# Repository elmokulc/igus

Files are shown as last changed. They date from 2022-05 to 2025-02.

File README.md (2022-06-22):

# IGUS : Linear Motion Device controlled by Arduino
Author: O. PERIA
---
## Linear module Features

- Part No. : STL-BB-0412
- Pitch : 1.5 mm (Tr08 x 1.5)

## Stepper motor Features

- Part No. : 17HM15-0904S (NEMA 17)
- Step angle : 0.9° (400 steps per revolution)

## Motor controller board Features

- Ref. : uStepper
-  Arduino compatible board with integrated stepper driver and 16-bit rotary encoder
- Limitswitch connected to pin PD2 (Digital input 2)

## Main commands

- H or H# : Moving Home
- P or P# : Getting current absolute step Position
- S or S# : Emmergency Stop
- h of h# : Printing Help
- R#[arg] : Moving [arg] steps Right - Example: R#10000
- L#[arg] : Moving [arg] steps Left

## Sources 
- Hardware : 
  - Seller website : [here](https://www.ustepper.com/getting-started-with-ustepper/)
  - Plugin to add to Arduino IDE: 
    - "ustepperS"
  - Additional Boards Managers URLS to add on Arduino IDE: 
    - [https://raw.githubusercontent.com/uStepper/uStepperHardware/master/package_ustepper_index.json](https://raw.githubusercontent.com/uStepper/uStepperHardware/master/package_ustepper_index.json)

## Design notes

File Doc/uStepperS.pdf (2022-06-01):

# uStepper S

# Product sheet

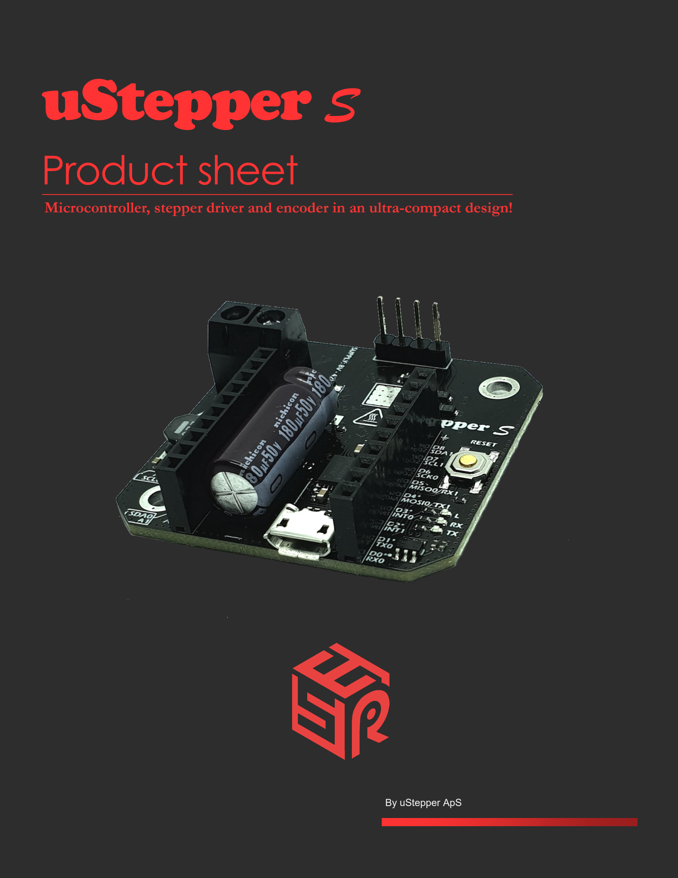
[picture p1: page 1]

By uStepper ApS

Microcontroller, stepper driver and encoder in an ultra-compact design!

Product: uStepper S

Document revision: 1.4

Author: MGN

Approved by: THO

Approval date: November 19th 2019 uStepper S incorporates a super silent stepper driver, high resolution encoder and Arduino

compatible MCU in a super slim design!

- Program uStepper with ease using the Arduino IDE and our extensive Arduino library !
- Make your stepper motor applications extremely compact !
- Make sure that you never miss a step again, thanks to the on-board encoder and control algorithm !

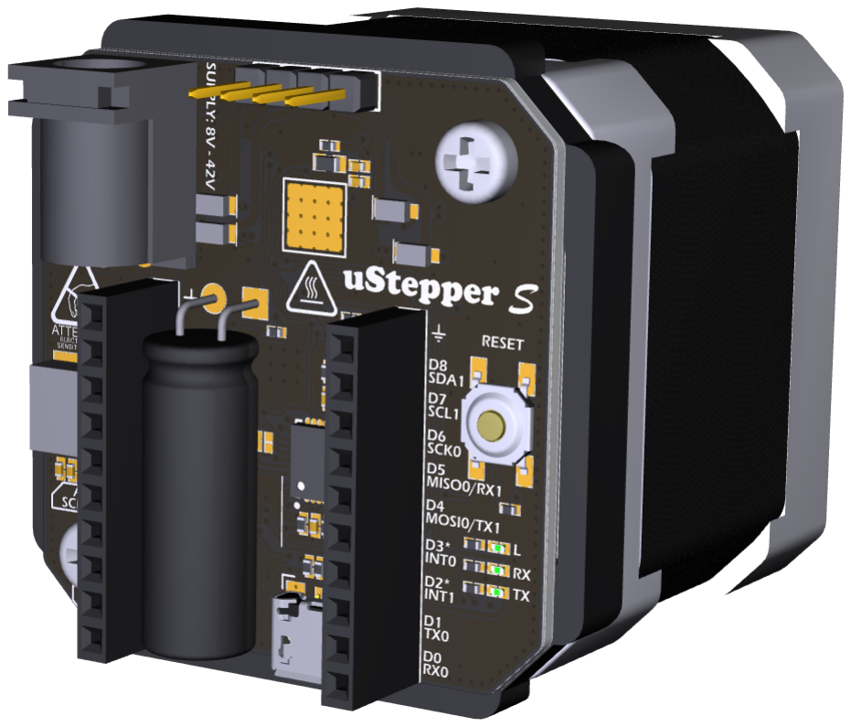
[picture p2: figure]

The super slim design of uStepper S makes it possible to develop applications using a stepper motor, without the need for long and messy wiring to an external Arduino/stepper shield. Furthermore the 16-bit rotary encoder ensures that the absolute position of the motor shaft can be tracked, enabling the uStepper S to detect any loss of steps and act on it !

## System overview

## uStepper S features

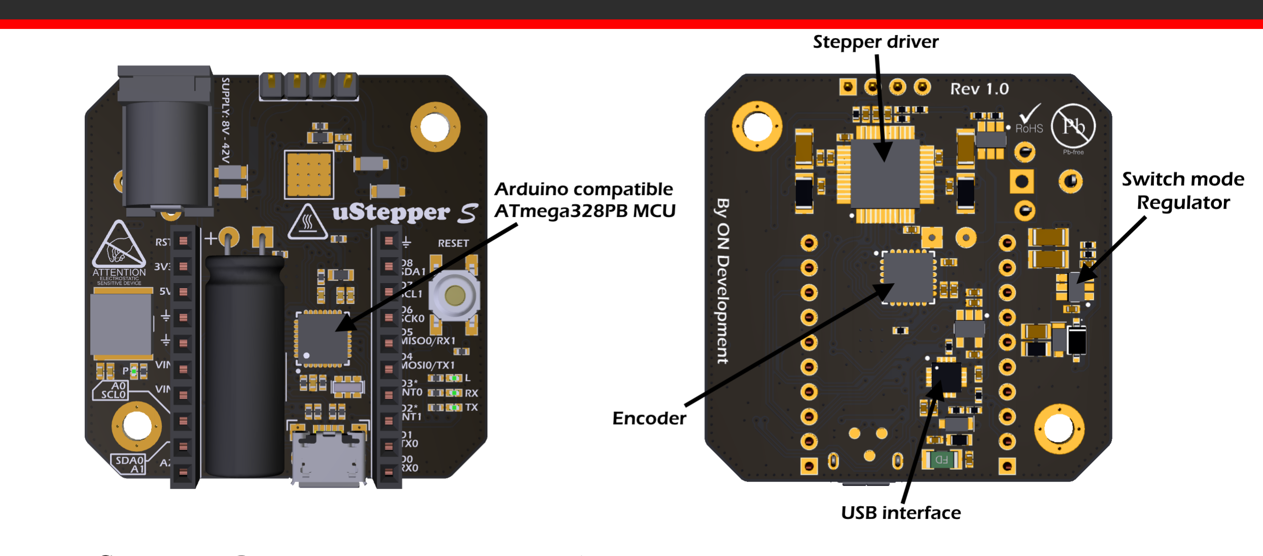
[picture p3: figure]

uStepper S has the following highlighted features:

- Compact design, fitting on the back of a NEMA 17 size stepper motor (41.8 mm x 41.8 mm)
- Incorporates the Trinamic TMC5130 with dynamic microstepping for very smooth operation with integrated ramp generator
- Driver delivers 2.5 A current (peak)
- New upgraded 328PB MCU from Microchip
- 16-bit encoder (0.0055 degrees resolution)
- Drive current is software controllable
- 12 I/O
- 3 Analog, 5 PWM
- 1 x SPI , 2 x UART, 2 x I2C
- Supply voltage 8 - 42 V
- Reverse polarity protection

Even though uStepper S features reverse polarity protection, it is always advisable to check the polarity before supplying power to the board in order to prevent damaging the board.

MCU

uStepper S uses the successor of the well tested and widely used ATmega328P - the ATmega328PB. Why? Because it does the job and does it good! The new upgraded ATmega328PB has been upgraded on multiple points including double USART, double I2C, double SPI and upgraded timers !

Stepper driver chip

The TMC5130 is a serious powerhouse and features a native 1/256th microstepping processing engine, complete with acceleration and deceleration ramping profiles, to give smooth transition to the desired speed. The native 1/256th microstepping not only ensures low noise levels and smooth operation, it also improves the precision of your application, by reducing the smallest step size of the motor to an astonishing 0.007 degrees (assuming a motor with 200 steps per revolution)! To put this into perspective, if the motor was mounted onto a CNC machine, where the axis moves 10 mm per full rotation, this would correspond to a resolution of 0.195 microns !

Encoder
The uStepper S uses the AEAT8800-Q24 encoder from Broadcom, delivering 16 bits resolution corresponding to 0.0055 degrees ! This is a perfect match for the TMC5130 with it’s native high resolution microstepping since this sensors is able to detect deviations just below the step resolution - enabling uStepper S to compensate properly.

Switch mode regulator
uStepper S Incorporates a switch mode regulator for delivering the 5 V logic supply. This is done to ensure that a supply voltage of up to 42 V can be applied ! The relatively high supply voltage has the benefit of increasing the stepper drivers ability to overcome the back EMF voltage generated by the motor, and hereby increasing the available torque at increasing velocities, compared to lower supply voltages.

## uStepper S features

## uStepper S pin mapping

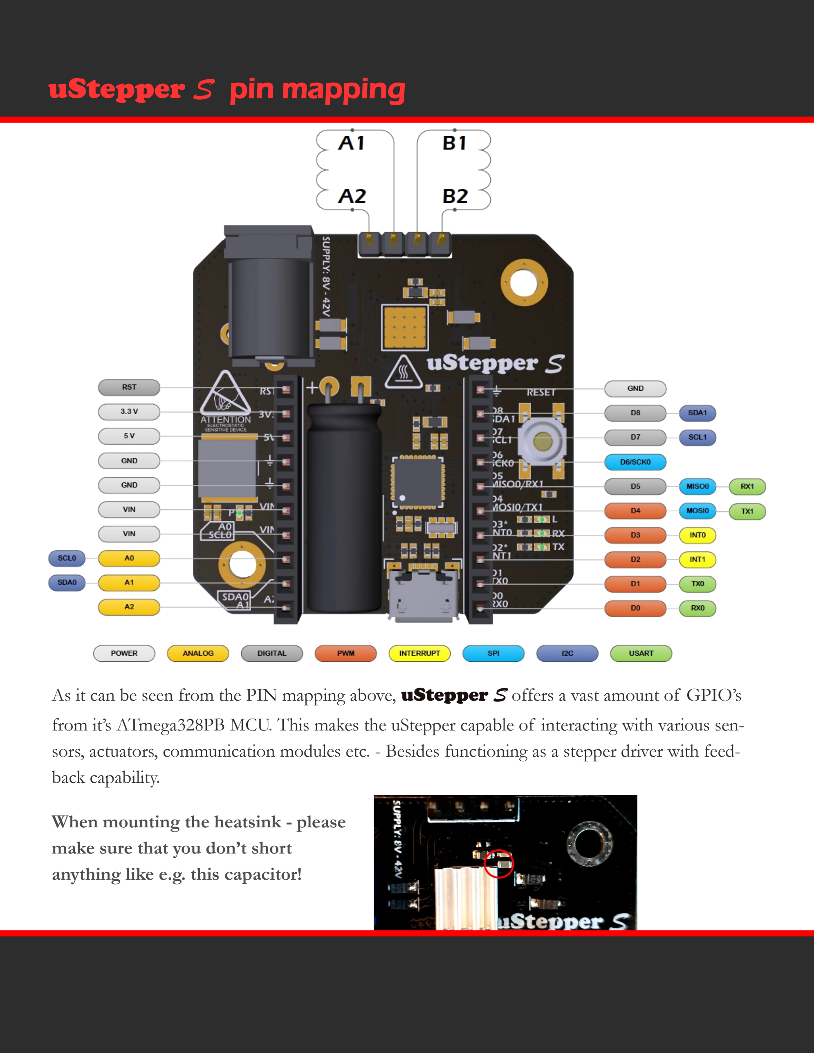
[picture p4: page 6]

As it can be seen from the PIN mapping above, uStepper S offers a vast amount of GPIO’s from it’s ATmega328PB MCU. This makes the uStepper capable of interacting with various sensors, actuators, communication modules etc. - Besides functioning as a stepper driver with feedback capability.

When mounting the heatsink - please
make sure that you don’t short anything like e.g. this capacitor!

## uStepper S characteristics

I/O Voltage | 5 V
Input Voltage (recommended) | 8 - 42 V
DC Current per I/O Pin (max) | 40 mA (max 200 mA total I/O draw)
DC Current for 5 V Pin (max) | 1000 mA
DC Current for 3.3 V Pin (max) | 150 mA
Stepper drive current | Up to 2.5 A (peak)
Dimensions | 41.8 x 41.8 x 14.5 mm
Weight | ~15g

Physical characteristics

Electrical characteristics

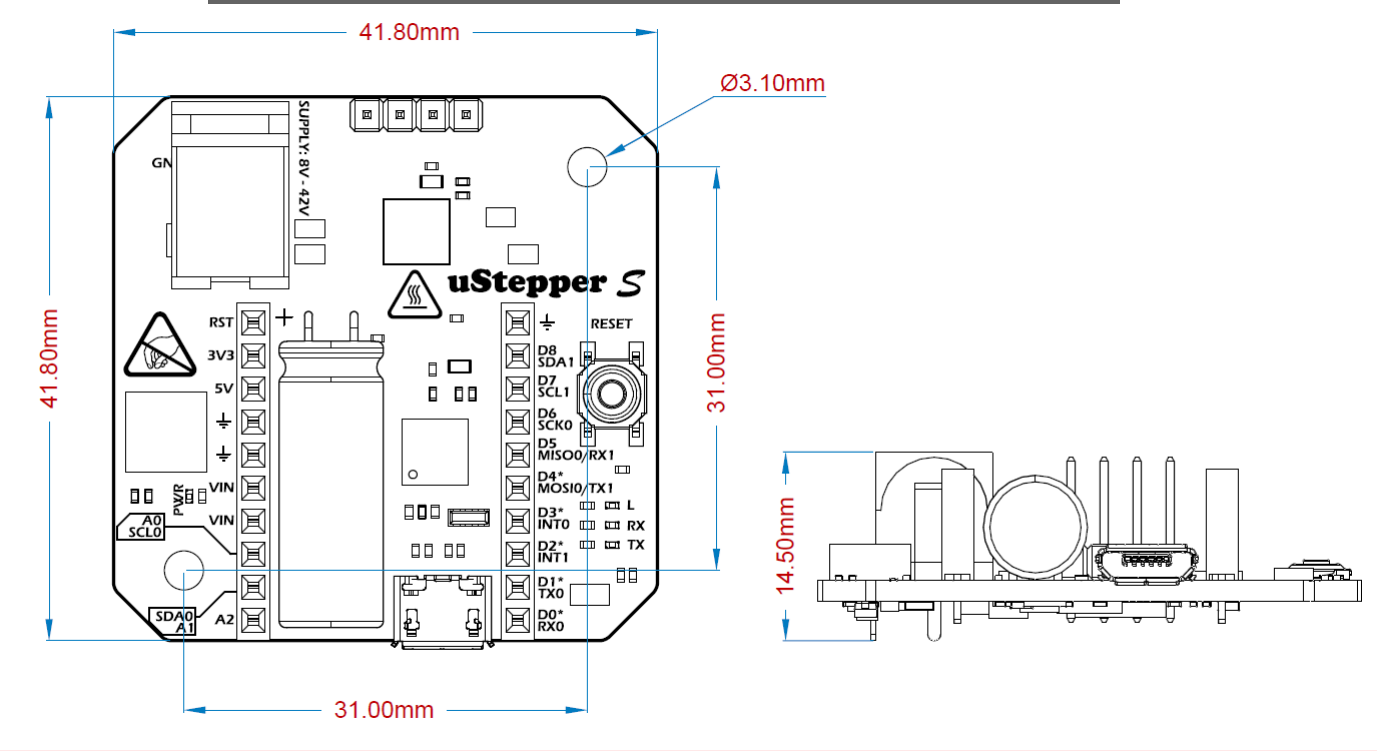
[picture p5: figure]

## uStepper S mounting

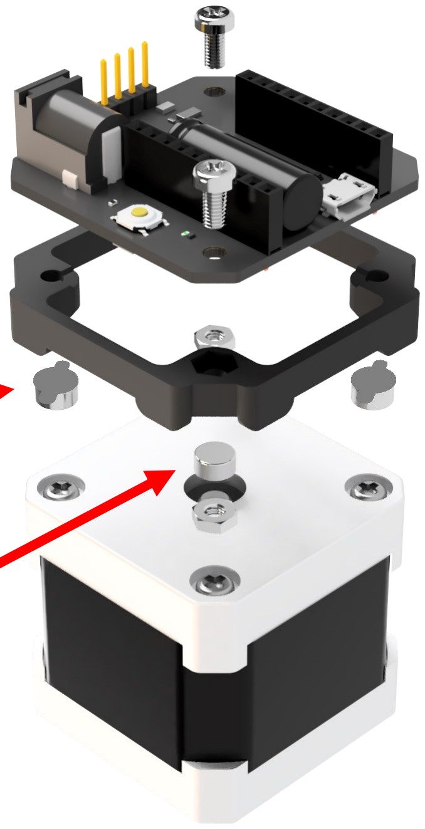
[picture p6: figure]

Diametrically magnetized encoder magnet

uStepper S comes with a bracket allowing two ways of mounting - magnet or permanent.

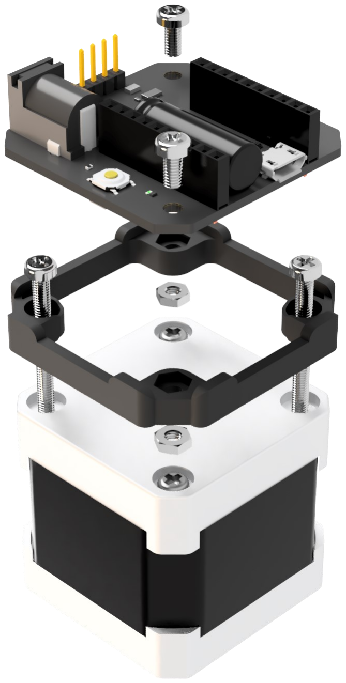
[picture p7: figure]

Permanent mount:

1.Remove two motor screws

2.Place encoder magnet on motor shaft

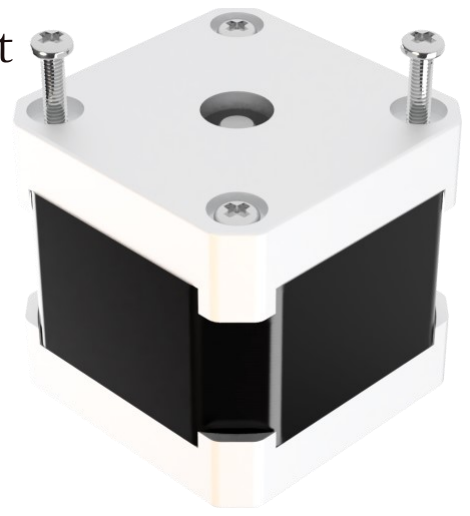
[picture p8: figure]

3.Insert nuts into bracket and mount bracket to motor w. two long screws

4.Secure uStepper S to the bracket with

Magnet mount:

1.Place encoder magnet on motor shaft

2.Add adhesive tape to mounting magnets

3.Insert mounting magnets into bracket

4.Secure uStepper S to the bracket with

## uStepper S FAQ

For information on how to setup uStepper in the Arduino IDE, visit our GitHub repository at www.github.com/uStepper or have a look at our videos on YouTube - search for uStepper.

More information/documentation on the uStepper Arduino library is also found in the readme section on out GitHub repository.

Q: I can’t program uStepper from the Arduino IDE, what is wrong?

A: Three most common issues:

1. If you use the Windows store app “Arduino IDE” you might experience problems. Download the executable or portable version of Arduino IDE from www.arduino.cc
2. Install hardware support and the uStepper S library
3. Remember to chose uStepper S as the board you program to

Q: When I run uStepper closed loop PID or Drop-in the motor spins up and runs fast in one direction, what is wrong?

A: Two most common issues:

1. Check that the encoder magnet is placed correctly on the motor shaft
2. Check that your PID parameters in the Arduino code are sane. A good starting point is to set P and I to 0.5 and D to 0.

For more FAQ visit www.ustepper.com !

## uStepper S getting started !

To get starter using uStepper S visit our instructive videos and GitHub documentation page pro-

vided below !

On GitHub you will see descriptions on how to set up uStepper S in the Arduino IDE and also find a link to the complete Arduino library documentation !

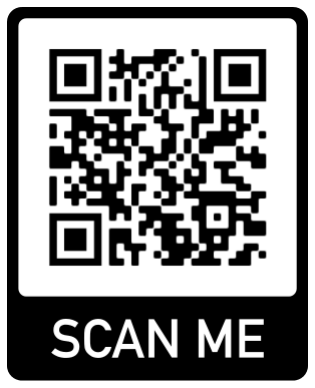
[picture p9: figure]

PRESS HERE (https://github.com/uStepper/uStepperS) to get to our GitHub or scan the code on the right !

Video Tutorials

On our YouTube channel you will find video tutorials on how to mount uStepper S, setting it up in the Arduino IDE and programming it. You will also find cool projects and application examples for uStepper S !

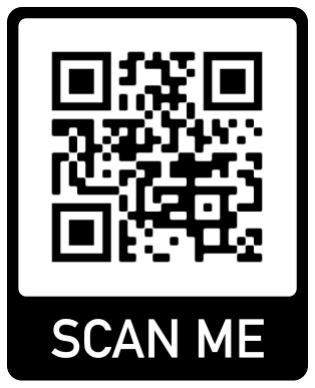
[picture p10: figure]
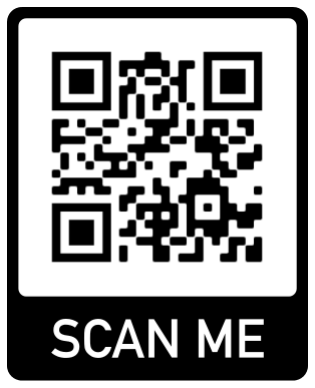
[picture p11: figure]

Mounting uStepper S (https://youtu.be/oYFnBv0kocI) | Programming uStepper S (https://youtu.be/V5M66Nhyn5s)

## uStepper S applications

Because of low cost and reliability stepper motors are favored over servo drives in a variety of ap-

plications, as for example robots, CNC machines, 3D-printers etc. With added feedback uStepper

can add a new dimension to stepper operation utilizing closed loop control or correction of

missed steps - making the stepper even more appealing than a more costly servo drive. With the

numerous features and the vast amount of I/O’s (including various busses), uStepper is the choice

for DIY hobbyists when in need of a reliable, precise and compact actuator for almost any applica-

tion.

Almost unlimited applications and ease of programming using the Arduino IDE also makes uStep-

per well suited for educational purposes !

### ”After all, learning just gets a bit more fun when there’s movement involved!”

## Disclaimer

1 Disclaimers and Limitation of Liability

1.1 uStepper ApS and/or ON Development IVS (or any individuals affiliated with either of the two companies) can not be held responsible for any damage inflicted upon mounting or interfacing with the uStepper board. This also includes damage to stepper motor (both electrical and mechanical) or any other 3rd party hardware connected to uStepper. Most stepper motor cases are made of aluminum, and care must be taken when preparing the mountings for uStepper.

1.2 By using the uStepper products (including, but not limited to, hardware and software) you acknowledge that uStepper ApS and/or ON Development IVS (or any individuals affiliated with either of the two companies) can not be held responsible for any personal injuries and/or damage to any 3rd party hardware that may occur when using the uStepper products.

1.3 To the extent permitted by law, uStepper ApS and/or ON Development IVS will not be liable for any indirect or consequential loss or damage, of any kind, (including without limitation loss of business, opportunity, data, profits) arising out of or in connection with the use of any products (including, but not limited to, hardware and software), developed, produced or sold by uStepper ApS and/or ON Development IVS (or any individuals affiliated with either of the two companies).

1.4 Nothing in these Terms and Conditions shall be construed so as to hold uStepper ApS and/or ON Development IVS liable for death or personal injury as a result of the negligence of uStepper ApS and/or ON Development IVS or that of its employees or agents.

2 Indemnity

2.1 You agree to indemnify and hold uStepper ApS and/or ON Development IVS and its employees and agents harmless from and against all liabilities, legal fees, damages, losses, costs and other expenses in relation to any claims or actions brought against uStepper ApS and/or ON Development IVS arising out of any breach by you of these Terms and Conditions or other liabilities arising out of your use of this Website.

2.2 You agree to indemnify and hold uStepper ApS and/or ON Development IVS and its employees and agents harmless from and against all liabilities, legal fees, damages, losses, costs and other expenses in relation to any claims or actions brought against uStepper ApS and/or ON Development IVS arising out of any breach by you of these Terms and Conditions or other liabilities arising out of your use of products(including, but not limited to, hardware and software) developed, produced or sold by uStepper ApS and/or ON Development IVS (or any individuals affiliated with either of the two companies).

3 Severance

If any of these Terms and Conditions should be determined to be invalid, illegal or unenforceable for any reason by any court of competent jurisdiction then such Term or Condition shall be severed and the remaining Terms and Conditions shall survive and remain in full force and effect and continue to be binding and enforceable.

## Contact

uStepper ApS
sales@ustepper.com

www.uStepper.com

© 2019 uStepper ApS All Rights Reserved

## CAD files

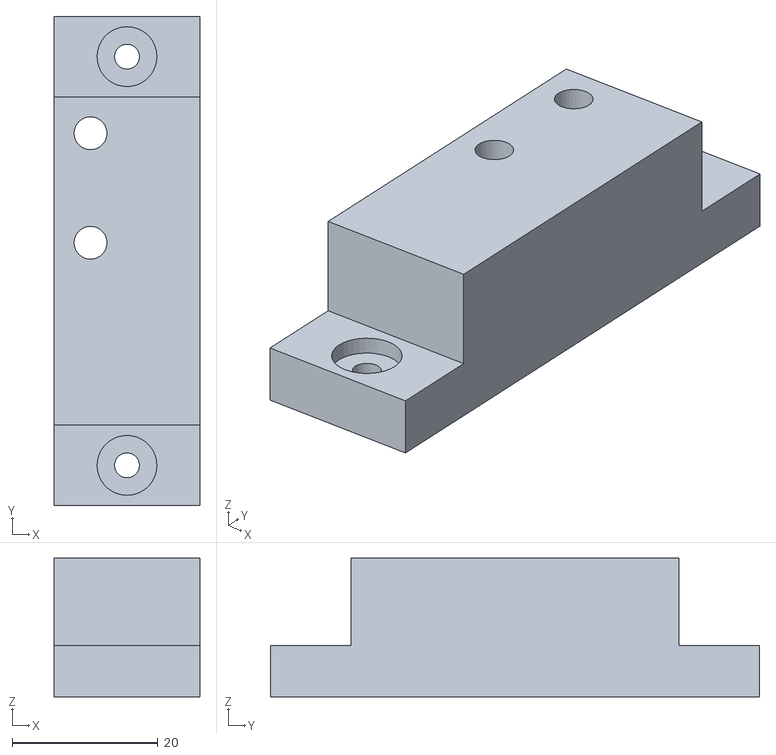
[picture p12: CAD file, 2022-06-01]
STL/TP_BASE_GAUCHE_02.STL
20.0 x 67.0 x 19.0

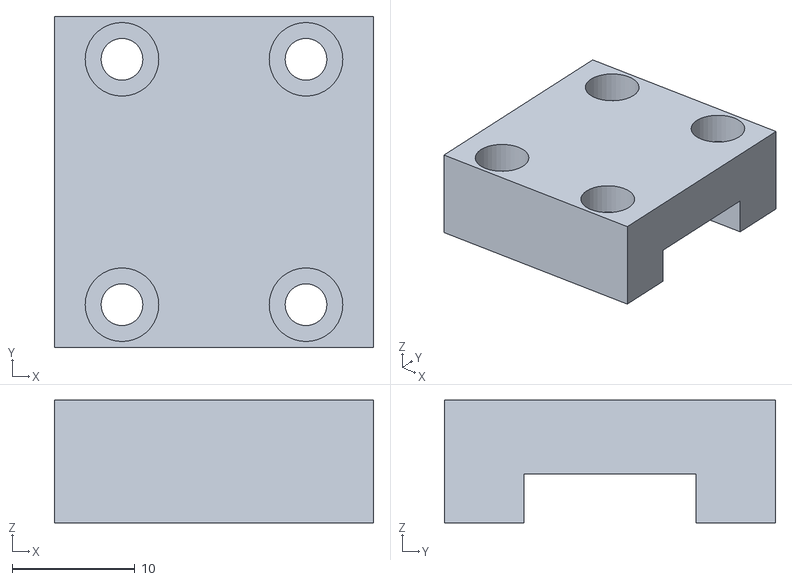
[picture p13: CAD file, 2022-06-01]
STL/TP_BUTEE_SWITCH_01.STL
26.0 x 27.0 x 10.0

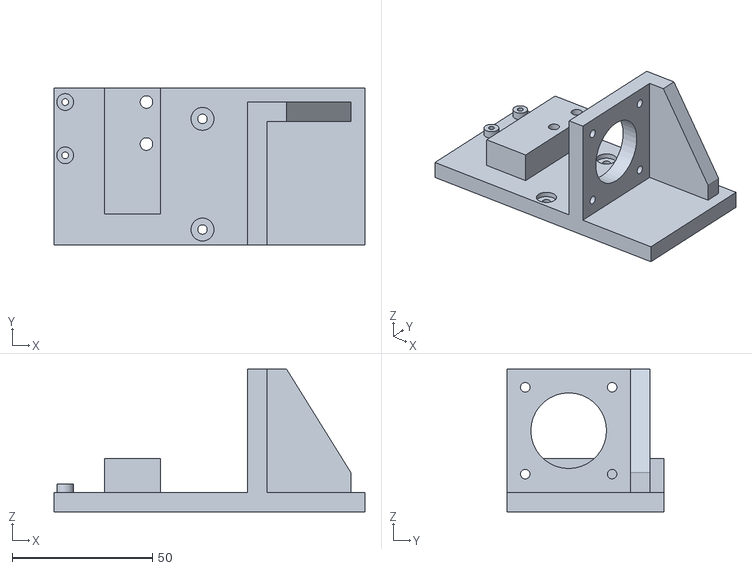
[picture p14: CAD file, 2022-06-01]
STL/TP_BASE_DROITE_02.STL
111.0 x 56.0 x 51.0

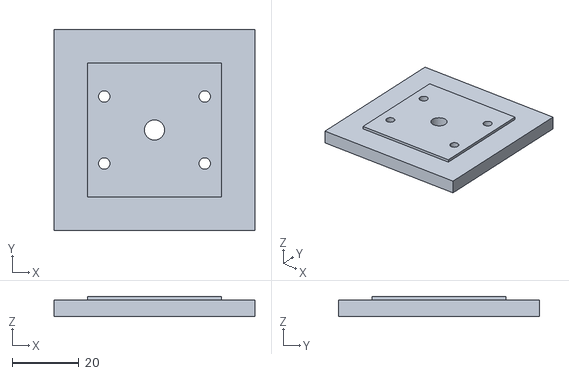
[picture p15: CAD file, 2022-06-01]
STL/TP_PLATEAU_01.STL
60.0 x 60.0 x 6.00

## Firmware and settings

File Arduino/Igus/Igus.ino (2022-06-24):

/********************************************************************************************
 *        File: Igus.ino                                                                     *
 *     Version: 1.0 Initial release                                                          *
 *        Date: May 19th, 2022                                                               *
 *      Author: Olivier PERIA                                                                *
 * Description: Drives Linear Motion Module IGUS                                             *
 *    Features: Possible commands sent to serial line :                                      *
 *                 H or H# : Moving Home                                                     *
 *                 P or P# : Getting current absolute step Position                          *
 *                 S or S# : Emmergency Stop                                                 *
 *                 h of h# : Printing Help                                                   *
 *                 R#[arg] : Moving [arg] steps Right - Example: R#10000                     *
 *                 L#[arg] : Moving [arg] steps Left                                         *
 ********************************************************************************************/

#include "Umotor.h"

#define LIMIT_STEP_MIN 0     // Motor Home position
#define LIMIT_STEP_MAX 45000 // Motor maximum position

#define VELOCITY_SLOW 200 // Slow velocity (steps/s)

#define ACCELERATION_SLOW 200  // Slow acceleration (steps/s^2)
#define ACCELERATION_FAST 1000 // Fast acceleration (steps/s^2)

#define LIMIT_SWITCH PD2 // Limit switch pin

#define CMD_DELIMITER '#' // Deliliter character
#define CMD_GOTORIGHT "R" // command : Move Right
#define CMD_GOTOLEFT "L"  // command : Move Left
#define CMD_GOHOME "H"    // command : Move Home
#define CMD_STOP "S"      // command : Emergency Stop
#define CMD_POSE "P"      // command : Get current absolute step Position
#define CMD_MODE "M"      // command : Request to change mode
#define CMD_HELP "h"      // command : Help

#define SET_VF "VF" // Set velocity fast

#define ACK_READY "READY"
#define ACK_START "MOVING..."
#define ACK_HOME "HOME POSITION"
#define ACK_INIT "MOVE HOME FIRST"
#define ACK_REACHED "POSITION REACHED"
#define ACK_WAIT "INVALID COMMAND WHILE MOVING"
#define ACK_ERROR "SYNTAX ERROR"
#define ACK_INVALID "INVALID ARGUMENT"
#define ACK_OUTRANGE "ARGUMENT OUT OF RANGE"
#define ACK_ABORTED "ABORTED"
#define ACK_RESET "MOTOR MUST BE RESETED"
#define ACK_DONE "CMD DONE"

#define MD_LINEAR 0
#define MD_ROTATE 1

typedef struct
{
  int32_t absSteps = 0; // Absolute step position (target position)
  int32_t nSteps = 0;   // Relative step position

} step_rcd;

Umotor stepperMotor(LIMIT_SWITCH); // Instantiates stepperMotor object with limit switch connected to LIMIT_SWITCH pin

step_rcd stepCntr; // Step counter (absolute and relative position)

uint8_t mMode; // Motor mode

int32_t VELOCITY_FAST = 100; // Fast velocity (steps/s) VMAX = 3000
uint8_t WK_MODE = MD_LINEAR; // Working mode can be : "MD_LINEAR", "MD_ROTATE" or "MD_SETUP"

/********************************************************************************************
 * Initializes the stepper motor and moves to initial position                               *
 ********************************************************************************************/
void setup()
{

  Serial.begin(9600);     // Sets the data rate for serial data transmission to 9600 baud
  Serial.setTimeout(100); // sets the maximum milliseconds to wait for serial data to 500

  // Setup stepperMotor
  stepperMotor.setup(NORMAL, STEP_REVOLUTION); // Normal mode (see Arduino UstepperS library)

  // Set stepperMotor driver direction
  stepperMotor.driver.setShaftDirection(1); // Inverted direction

  // Set motor brake mode when motor is stopped
  stepperMotor.setBrakeMode(COOLBRAKE);

  Serial.println(ACK_READY);
}

/********************************************************************************************
 * Main loop                                                                                 *
 ********************************************************************************************/
void loop()
{
  // Reads and interprets the commands sent to serial line
  if (Serial.available())
    commandInterpreter(&stepperMotor, &stepCntr);

  if (WK_MODE == MD_LINEAR)
  {
    // Lost steps detection and correction
    mMode = stepperMotor.getMotorMode();
    if ((mMode != MOTOR_INIT) && (mMode != MOTOR_ABORTED))
    {
      // Motor not checked and Driver position reached
      if ((mMode != MOTOR_CHECKED) && (stepperMotor.getMotorState(POSITION_REACHED) == 0))
      {
        // Updates absolute step position
        if (mMode == MOTOR_RUNNING_RIGHT)
          stepCntr.absSteps += stepCntr.nSteps;
        else if (mMode == MOTOR_RUNNING_LEFT)
          stepCntr.absSteps -= stepCntr.nSteps;
        // Checks and corrects lost steps
        checkSteps(&stepperMotor, &stepCntr);
        Serial.println(ACK_REACHED);
      }
    }
  }
  else if (WK_MODE == MD_ROTATE)
  {
    // Lost steps detection and correction
    mMode = stepperMotor.getMotorMode();
    if (mMode != MOTOR_ABORTED)
    {
      // Motor not checked and Driver position reached
      if ((mMode != MOTOR_CHECKED) && (stepperMotor.getMotorState(POSITION_REACHED) == 0))
      {
        // Updates absolute step position
        if (mMode == MOTOR_RUNNING_RIGHT)
          stepCntr.absSteps += stepCntr.nSteps;
        else if (mMode == MOTOR_RUNNING_LEFT)
          stepCntr.absSteps -= stepCntr.nSteps;
        // Checks and corrects lost steps
        // checkSteps(&stepperMotor, &stepCntr);
        stepperMotor.setMotorMode(MOTOR_CHECKED);
        Serial.println(ACK_REACHED);
      }
    }
  }
}

/********************************************************************************************
 * Reads and interprets the commands sent to serial line                                     *
 *                                                                                           *
 * input : motor : stepper motor                                                             *
 *         pose  : absolute and relative step positions                                      *
 ********************************************************************************************/
void commandInterpreter(Umotor *motor, step_rcd *pose)
{
  // Gets motor mode
  uint8_t mMode = motor->getMotorMode();

  // If motor aborted after emergency stop command sent
  if (mMode == MOTOR_ABORTED)
  {
    Serial.println(ACK_RESET);
    String str = Serial.readString(); // Clear serial buffer
  }

  // Else motor normaly stopped and checked
  else
  {
    // Gets the String read from the serial buffer, up to the delimiter character CMD_DELIMITER if found, or the entire
    // buffer if not found (after timeout defined in setup()). The delimiter character is not returned in the string
    String cmdString = Serial.readStringUntil(CMD_DELIMITER);

    // Command Emergency Stop
    if (cmdString.equals(CMD_STOP))
    {
      motor->stop(HARD);
      motor->setMotorMode(MOTOR_ABORTED);
      Serial.println(ACK_ABORTED);
    }

    // Command Move Right
    else if (cmdString.equals(CMD_GOTORIGHT))
    {
      // Motor normally stopped and checked
      if (mMode == MOTOR_CHECKED)
      {
        // Looks for the next valid integer in the serial buffer, returns 0 if not found (after timeout defined in setup())
        pose->nSteps = int32_t(Serial.parseInt());
        if (WK_MODE == MD_LINEAR){
            if (pose->nSteps <= 0)
              Serial.println(ACK_INVALID);
            else if ((pose->absSteps + pose->nSteps) > LIMIT_STEP_MAX)
              Serial.println(ACK_OUTRANGE);
            else
            {
              Serial.println(ACK_START);
              motor->rotateSteps(pose->nSteps, DIR_RIGHT, ACCELERATION_FAST, VELOCITY_FAST);
            }
          }
        else if (WK_MODE == MD_ROTATE){
            if (pose->nSteps <= 0)
              Serial.println(ACK_INVALID);
            else
            {
              Serial.println(ACK_START);
              motor->rotateSteps(pose->nSteps, DIR_RIGHT, ACCELERATION_FAST, VELOCITY_FAST);
            }
          }
      }
      // Motor must moved Home first
      else if (mMode == MOTOR_INIT)
      {
        Serial.readString(); // Clear serial buffer
        Serial.println(ACK_INIT);
      }
      // Motor moving
      else
      {
        Serial.readString(); // Clear serial buffer
        Serial.println(ACK_WAIT);
      }
    }

    // Command Move Left
    else if (cmdString.equals(CMD_GOTOLEFT))
    {
      // Motor normally stopped and checked
      if (mMode == MOTOR_CHECKED)
      {
        // Looks for the next valid integer in the serial buffer, returns 0 if not found (after timeout defined in setup())
        pose->nSteps = int32_t(Serial.parseInt());
        if (WK_MODE == MD_LINEAR){
            if (pose->nSteps <= 0)
              Serial.println(ACK_INVALID);
            else if ((pose->absSteps + pose->nSteps) > LIMIT_STEP_MAX)
              Serial.println(ACK_OUTRANGE);
            else
            {
              Serial.println(ACK_START);
              motor->rotateSteps(pose->nSteps, DIR_LEFT, ACCELERATION_FAST, VELOCITY_FAST);
            }
          }
        else if (WK_MODE == MD_ROTATE){
            if (pose->nSteps <= 0)
              Serial.println(ACK_INVALID);
            else
            {
              Serial.println(ACK_START);
              motor->rotateSteps(pose->nSteps, DIR_LEFT, ACCELERATION_FAST, VELOCITY_FAST);
            }
          }
      }
      // Motor must move Home first
      else if (mMode == MOTOR_INIT)
      {
        Serial.readString(); // Clear serial buffer
        Serial.println(ACK_INIT);
      }
      // Motor moving
      else
      {
        Serial.readString(); // Clear serial buffer
        Serial.println(ACK_WAIT);
      }
    }

    // Command Move Home
    else if (cmdString.equals(CMD_GOHOME))
    {
      // Motor normally stopped and checked
      if ((mMode == MOTOR_INIT) || (mMode == MOTOR_CHECKED))
      {
        Serial.println(ACK_START);
        MoveToInitialPosition(motor, pose);
        Serial.println(ACK_HOME);
      }
      // Motor moving
      else
      {
        Serial.readString(); // Clear serial buffer
        Serial.println(ACK_WAIT);
      }
    }

    // Command Get Absolute Step Position
    else if (cmdString.equals(CMD_POSE))
    {
      // Motor must move Home first
      if (mMode == MOTOR_INIT)
      {
        Serial.readString(); // Clear serial buffer
        Serial.println(ACK_INIT);
      }
      else
        Serial.println(stepperMotor.getEncoderSteps());
    }

    // Command Help
    else if (cmdString.equals(CMD_HELP))
    {
      Serial.println("H or H# : Moving Home");
      Serial.println("P or P# : Getting current absolute step Position");
      Serial.println("S or S# : Emmergency Stop");
      Serial.println("h of h# : Printing Help");
      Serial.println("R#[arg] : Moving [arg] steps Right - Example: R#10000");
      Serial.println("L#[arg] : Moving [arg] steps Left");
      Serial.println("M#[arg] : Switch mode 0=LINEAR 1=ROTATE - Example: M#0");
      Serial.println("VF#[arg] : Set max velocity (max=3000) - Example: VF#1000");
    }

    else if (cmdString.equals(CMD_MODE))
    {

      WK_MODE = int32_t(Serial.parseInt());
      Serial.readString(); // Clear serial buffer
      String workMode = GetWorkMode(WK_MODE);
      Serial.print(ACK_DONE);
      Serial.print(" Mode=");
      Serial.println(workMode);
    }

    else if (cmdString.equals(SET_VF))
    {

      VELOCITY_FAST = int32_t(Serial.parseInt());
      Serial.readString(); // Clear serial buffer
      Serial.print(ACK_DONE);
      Serial.print(" VELOCITY_FAST=");
      Serial.println(VELOCITY_FAST);
    }

    // Command not found
    else
      Serial.println(ACK_ERROR);
  }
}

/********************************************************************************************
 * Moves the carriage to initial position                                                    *
 *                                                                                           *
 * input : motor : stepper motor                                                             *
 *         pose  : rbsolute and relative step positions                                      *
 ********************************************************************************************/
void MoveToInitialPosition(Umotor *motor, step_rcd *pose)
{
  int32_t nMstps;

  // Set motor acceleration and velocity
  motor->setMaxAcceleration(ACCELERATION_FAST); // Fast acceleration
  motor->setMaxVelocity(VELOCITY_FAST);         // Fast velocity

  // Move carriage left to limit switch
  if (!motor->getLimitSwitchState())
  {                           // Limit switch not pressed
    motor->runContinous(CCW); // Move carriage left
    while (!motor->getLimitSwitchState())
      ;                // Wait for limit switch pressed
    motor->stop(HARD); // Stop carriage
  }

  // Move carriage 600 steps right
  motor->rotateSteps(600, DIR_RIGHT, ACCELERATION_FAST, VELOCITY_FAST);

  // Wait for motor stopped
  while (motor->getMotorState(POSITION_REACHED))
    ;

  // Set motor acceleration and velocity
  motor->setMaxAcceleration(ACCELERATION_SLOW); // Slow acceleration
  motor->setMaxVelocity(VELOCITY_SLOW);         // Slow velocity

  // Move carriage left to limit switch
  if (!motor->getLimitSwitchState())
  {                           // Limit switch not pressed (HIGH)
    motor->runContinous(CCW); // Move carriage left
    while (!motor->getLimitSwitchState())
      ;                // Wait for limit switch pressed
    motor->stop(HARD); // Stop carriage
  }

  // Move carriage 800 steps right
  motor->rotateSteps(800, DIR_RIGHT, ACCELERATION_SLOW, VELOCITY_SLOW);

  // Wait for position reached
  while (motor->getMotorState(POSITION_REACHED))
    ;

  // Reset driver and encoder step counters
  motor->driver.setHome();
  motor->encoder.setHome();

  // Reset motor step positions
  pose->absSteps = 0;
  pose->nSteps = 0;

  // Activates Motor brake
  motor->setBrakeMode(COOLBRAKE);

  // Set motor mode to CHECKED (target position reached)
  motor->setMotorMode(MOTOR_CHECKED);
}

/********************************************************************************************
 * Lost steps detection and correction                                                       *
 *                                                                                           *
 * Compares the encoder step counter (real position) with the motor step counter (target     *
 * position). If different, move the motor to make the encoder step position equal to the    *
 * motor step position                                                                       *
 *                                                                                           *
 * input : motor : stepper motor                                                             *
 *         pose  : absolute and relative step positions                                      *
 ********************************************************************************************/

void checkSteps(class Umotor *motor, step_rcd *pose)
{
  // Error between Motor target step position and Encoder real step position
  int32_t deltaSteps = pose->absSteps - motor->getEncoderSteps();

  while (deltaSteps != 0)
  {

    if (deltaSteps > 0)
      motor->rotateSteps(deltaSteps, DIR_RIGHT, ACCELERATION_FAST, VELOCITY_FAST); // Move right
    else
      motor->rotateSteps(int32_t(-1) * deltaSteps, DIR_LEFT, ACCELERATION_SLOW, VELOCITY_SLOW); // Move left

    while (motor->getMotorState(POSITION_REACHED))
      ; // Wait for position reached

    deltaSteps = pose->absSteps - motor->getEncoderSteps();
  }

  motor->setMotorMode(MOTOR_CHECKED);
}

/********************************************************************************************
 * Change distance to steps                                                                  *
 *                                                                                           *
 *  input : dist : distance in mm                                                            *
 * return : fullsteps                                                                        *
 ********************************************************************************************/
int32_t DistanceToSteps(float dist)
{
  int32_t nStps = int32_t(0.5 + dist * float(STEP_REVOLUTION) / 1.5); // 1.5 mm per revolution

  return (nStps);
}

String GetWorkMode(int MODE)
{
  String str;
  if (MODE == 0)
    str = "LINEAR";
  else
    str = "ROTATE";
  return str;
}

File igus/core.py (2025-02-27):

import serial
from threading import Thread
from functools import wraps
from time import sleep
import glob 
import sys
import logging


LOG_DEFAULT_FORMATTER = logging.Formatter(
    "[%(asctime)s:%(levelname)s:%(filename)s:%(lineno)d:%(funcName)s()]: [%(message)s]"
)

def serial_ports():
    """ Lists serial port names

        :raises EnvironmentError:
            On unsupported or unknown platforms
        :returns:
            A list of the serial ports available on the system
    """
    if sys.platform.startswith('win'):
        ports = ['COM%s' % (i + 1) for i in range(256)]
    elif sys.platform.startswith('linux') or sys.platform.startswith('cygwin'):
        # this excludes your current terminal "/dev/tty"
        ports = glob.glob('/dev/tty[A-Za-z]*')
    elif sys.platform.startswith('darwin'):
        ports = glob.glob('/dev/tty.*')
    else:
        raise EnvironmentError('Unsupported platform')

    result = []
    for port in ports:
        try:
            s = serial.Serial(port)
            s.close()
            result.append(port)
        except (OSError, serial.SerialException):
            pass
    return result

def thrd(f):
    ''' This decorator executes a function in a Thread'''
    @wraps(f)
    def wrapper(*args, **kwargs):
        thr = Thread(target=f, args=args, kwargs=kwargs)
        thr.start()
        
    return wrapper

class IGUS:
    def __init__(self, port='/dev/ttyUSB0', baudrate=9600, timeout=1):
        self.port = port
        self.baudrate = baudrate
        self.timeout = timeout       
        self.on_move = False
        self.pattern_flag = False
        self.pass_check = False
        self.CONST_REV = 0.00375 # mm/step
        
        self.warning_words = [
        "ACK_WAIT"    ,
        "ACK_ERROR"      ,
        "ACK_INVALID"   ,
        "ACK_OUTRANGE"  ,
        "ACK_ABORTED"   ,
        "ACK_RESET"]

        self.setup_logger()        
        self.connect()  
    
    def setup_logger(self):
        # Configuration du logger
        self.logger = logging.getLogger(f"{IGUS.__name__}")
        handler = logging.StreamHandler()  # Sortie des logs sur la console
        handler.setFormatter(LOG_DEFAULT_FORMATTER)
        self.logger.addHandler(handler)
        self.logger.setLevel(logging.INFO)  # Niveau par défaut
        self.logger.propagate = False  # Évite la duplication des logs
    
    def update_constant_rev(self, nb_step_per_tr=400, dist_per_tr=1.5):
        """_summary_

        Args:
            nb_step_per_tr (int, optional): Number of motor step to make one tour. Defaults to 400.
            dist_per_tr (float, optional): Displacement for one motor tour expressed in mm. Defaults to 1.5.
        """
        self.CONST_REV = dist_per_tr/nb_step_per_tr
    
        
    def connect(self):
        self.ser = serial.Serial(port=self.port, baudrate=self.baudrate, timeout=self.timeout)
        self.read_msg()
        self.read_msg()
    
    def reconnect(self):
        self.ser.close()
        self.connect()
        
    def close(self):
        self.ser.close()
    
    def read_msg(self):
        msg=""
        while True:
            line = self.ser.readline().decode('utf-8')
            if line:
                msg += line                        
            else:
                break                   
        if msg:
            self.logger.info(f"received message: {msg}")
            return msg
            
    def send_msg(self, msg):
        if msg != 'S':
            while self.on_move:
                pass
        self.ser.write(str.encode(msg))
        
    def display_help(self):
        self.send_msg('h')
        self.read_msg()
        
    def move_stop(self):
        self.send_msg('S')
        self.read_msg()
        
    def move_home(self):
        self.send_msg('H')
        self.check_cmd(reach_msg='HOME POSITION') 
           
    def move_position(self, value, unit="mm", direction="R"):
        """_summary_
        Move linear module to
        Args:
            value (_type_): value to move
            unit (str, optional): can be mm or step. Defaults to "mm".
            direction (str, optional): can be R or L. Defaults to "R".
        """
        
        if unit == "mm":
            value = value / self.CONST_REV
            self.logger.info(f'{direction} -- {round(value*self.CONST_REV)} -- mm ')
        else:
            self.logger.info(f'{direction} -- {value} -- step ')
        value = round(value)
        self.send_msg(f'{direction}#{value}')
        self.check_cmd(reach_msg='POSITION REACHED')

    @thrd
    def check_cmd(self, reach_msg='POSITION REACHED'):
        self.on_move = True
        while True:
            msg = self.read_msg()
            if self.pass_check:
                self.logger.info("Passing check")
                break
            if type(msg) != type(None):
                if reach_msg in msg:
                    break
                elif msg in self.warning_words:
                    self.logger.info(f"Warning: {msg}")
                    break
            self.logger.info("Waiting for confirmation...")
        self.on_move = False
        self.pass_check = False
        
    def get_meters_value(self, value):
        """_summary_
        Return step value in mm
        Args:
            value (_type_): _description_

        Returns:
            _type_: _description_
        """
        return value*self.CONST_REV
    
    
    
    @thrd  
    def run_pattern(self, values, unit="mm", direction="R"):
        """_summary_

        Args:
            values (_type_): array of values to move
            unit (str, optional): _description_. Defaults to "mm".
            direction (str, optional): _description_. Defaults to "R".
        """
        for value in values:
            while (self.on_move or not self.pattern_flag):
                pass
            self.move_position(value=value, unit=unit, direction=direction) 
            self.pattern_flag = False

    def get_current_position(self, unit="mm"):
        self.send_msg('P')
        if unit == "mm":
            return float(self.get_meters_value(float(self.read_msg())))
        else : 
            return float(self.read_msg())
            
    def set_max_velocity(self, value):
        self.send_msg(f'VF#{value}')
        self.check_cmd(reach_msg='CMD DONE')


    def set_mode(self, mode="linear"):
        map_dic = {
            "linear":0,
            "rotate":1
        }        
        self.send_msg(f'M#{map_dic[mode]}')
        self.check_cmd(reach_msg='CMD DONE')

if __name__ == '__main__':
    # values = [10, 20, 30, 35]
    igus = IGUS(port="/dev/ttyUSB3")
    igus.set_mode("rotate")
    # igus.move_home()
    # igus.run_pattern(values, unit="mm", direction="R")
    # igus.display_help()
    # print(serial_ports())
    
    

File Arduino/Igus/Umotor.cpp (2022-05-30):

/********************************************************************************************
*        File: Umotor.ccp														                                        *
*		  Version: 1.0 Initial release                                         				  		    *
*        Date: May 19th, 2022  	                                         			              *
*      Author: Olivier PERIA                                          					            *
* Description: Umotor class implementation used with the the uStepperS Arduino library      *
*    Features: - Gets the position of the motor driver                                      *
*              - Gets the position of the motor encoder                                     *
*              - Gets the motor limit switch state                                          *
*              - Gets the motor state                                                       *
*              - Sets the motor state                                                       *
*              - Makes the motor rotate a predefined number of steps                        *
********************************************************************************************/

#include "Umotor.h"



/********************************************************************************************
* Umotor class constructor                                                                  *
* - Inherites of uStepperS class defined in uStepperS Arduino library                         *
* - Initiates the motor limit switch pin and the motor mode                                   *
*                                                                                           *
* input : pin : Limit switch pin                                                            *
********************************************************************************************/
Umotor::Umotor(int pin) : uStepperS()
{
  switchPin = pin; 
  pinMode(switchPin, INPUT);  // Sets digital pin mode to INPUT

  motorMode = MOTOR_INIT;     // Sets initial motor mode to INIT
}



/********************************************************************************************
* Gets the current position of the driver from reference position. The reference position   *
* can be reseted at any time by using the driver.setHome() function                         *
*                                                                                           *
* return : number of fullsteps                                                              *
********************************************************************************************/
int32_t Umotor::getDriverSteps()
{
  // Position read in microsteps and converted to fullsteps (MICRO_STEP microsteps per fullsteps)
  int32_t drvStps = int32_t(0.5 + float(driver.getPosition()) / float(MICRO_STEP));
  
  return(drvStps);
}



/********************************************************************************************
* Gets the current position of the encoder from reference position. The reference position  *
* can be reseted at any time by using the encoder.setHome() function                        *
*                                                                                           *
* return : number of fullsteps                                                              *
********************************************************************************************/
int32_t Umotor::getEncoderSteps()
{
  // Position read in raw data and converted to fullsteps (2^16 positions per revolution)
  int32_t encStps = int32_t(0.5 + float(encoder.getAngleMovedRaw(false)) * float(STEP_REVOLUTION) / 65536.0);

  return(encStps);
}



/********************************************************************************************
* Gets the motor limit switch state                                                         *
*                                                                                           *
* return : true  : switch activated                                                         *
*          false : switch not activated                                                     *
********************************************************************************************/
boolean Umotor::getLimitSwitchState()
{
  if (digitalRead(switchPin)) return(false);  // Limit switch not pressed
    else return(true);                        // Limit switch pressed
}



/********************************************************************************************
* Gets the motor state                                                                      *
*                                                                                           *
* return : MOTOR_STOPPED : motor normaly stopped                                            *
*          MOTOR_ABORTED : motor stopped after emergency stop                               *
*          MOTOR_CHECKED : lost steps checked and corrected (position reached)              *
*          MOTOR_RUNNING_RIGHT : motor is moving right                                      *
*          MOTOR_RUNNING_LEFT  : motor is moving left                                       *
********************************************************************************************/
uint8_t Umotor::getMotorMode()
{
  return(motorMode);
}



/********************************************************************************************
* Sets the motor state                                                                      *
*                                                                                           *
* input : mode : Motor state - Possible values :                                            *
*                     MOTOR_STOPPED : motor normaly stopped                                 *
*                     MOTOR_ABORTED : motor stopped after emergency stop                    *
*                     MOTOR_CHECKED : lost steps checked and corrected (position reached)   *
*                     MOTOR_RUNNING_RIGHT : motor is moving right                           *
*                     MOTOR_RUNNING_LEFT  : motor is moving left                            *
********************************************************************************************/
void Umotor::setMotorMode(uint8_t mode)
{
  motorMode = mode;
}
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

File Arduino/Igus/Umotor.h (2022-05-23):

/********************************************************************************************
*        File: Umotor.h 														                                        *
*		  Version: 1.0 Initial release                                         				  		    *
*        Date: May 19th, 2022  	                                         			              *
*      Author: Olivier PERIA                                          					            *
* Description: Umotor class implementation used with the the uStepperS Arduino library      *
*    Features: - Gets the current position of the motor driver                              *
*              - Gets the encoder step counter value                                        *
*              - Gets the motor limit switch state                                          *
*              - Gets the motor state                                                       *
*              - Sets the motor state                                                       *
*              - Makes the motor rotate a predefined number of steps                        *
********************************************************************************************/

#ifndef Umotor_h
#define Umotor_h

#include <Arduino.h>
#include <uStepperS.h>

#define STEP_REVOLUTION 400   // Mumber of steps per revolution
#define MICRO_STEP      256   // Driver internal position counter is 256 microsteps per step

#define DIR_RIGHT  0  // Right Direction
#define DIR_LEFT   1  // Left Direction

#define MOTOR_INIT           0    // Motor mode : Initialized
#define MOTOR_ABORTED        1    // Motor mode : Stopped while moving (emergency stop)
#define MOTOR_CHECKED        2    // Motor mode : Checked (position reached)
#define MOTOR_RUNNING_RIGHT  3    // Motor mode : Running Right
#define MOTOR_RUNNING_LEFT   4    // Motor mode : Running Left
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

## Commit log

2022-05-16 New class motor
2022-06-01 Add reference documents
    [TP_BASE_DROITE_02.STL, TP_BASE_GAUCHE_02.STL, TP_BUTEE_SWITCH_01.STL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]
2022-06-24 Enhance print ACK_DONE
